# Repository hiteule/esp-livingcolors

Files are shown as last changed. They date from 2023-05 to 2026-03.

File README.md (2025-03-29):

# ESP LivingColors

An electronic board designed to integrate a LivingColor lamp gen1 in [HomeAssistant].
The board is based on an ESP8266 & [ESPHome] to integrate the LivingColors lamp in HomeAssistant.
The communication with the lamp is managed by an Atmega328 microcontroller & a CC2500 module (2.4ghz RF transceiver).
The ESP8266 & Atmega328 communicate through an I2C bus.

:warning: This board ONLY works with the 1st generation LivingColors.

## PCB

The card must be powered with 5V via the J1 connector.

The Atmega328 can be flashed via JP1. The ESP8266 can be flashed via JP3.
For this, you can use my [ESP/Atmega programmer].

The card was designed with [Eagle].
The additional [libraries] used are:
* 74LVC125AD.lbr
* ATMEGA328P-AU.lbr
* CC2500.lbr
* CONNECTORS.lbr
* ESP-12F.lbr
* TXS0104EPWR.lbr
* regulator.lbr

## Software

### Atmega

The Atmega is controling the LivingColors via RF (like your conventional remote control).
We use Arduino bootloader. If it not already the case, you should install it on your Atmega.
To communicate in RF, we use the library made by [George Knutsel]. Thanks to him!

#### Flash the firmware

* Install the Arduino IDE.
* Put the `LivingColors` library in the right Arduino Library folder.
* Plug the board to your computer with JP1 and the [ESP/Atmega programmer] (for the Atmega, you don't need to power it).
* Open the firmware with the Arduino IDE and flash the Atmega.

Now, you can unplug the Atmega and go to the next step.

### ESP

The ESP is exposing the LivingColors in Home Assisant. To do it, we use [ESPHome].
To do so:
* Install the ESPHome module on HomeAssistant.
* Plug the board to your computer with JP3 and the [ESP/Atmega programmer]. Don't forget to power the programmer with an external power source between 3.3V and 12V.
* In the ESPHome module, create a new device.
* Update your ESPHome device with the `livingcolors.yaml` file.
* Install it on the ESP.

Now you can unplug the ESP from your computer and power the board via JP1.
ESP should boot normally and the LivingColors should be visible in HomeAssistant.

## How to use it ?

### Register the remote address

To be able to communicate with the LivingColors, you need to extract and register the remote address.

* Hold the `SW_LEARN` switch and power on the board to enter in the learning mode.
* The LED will light up for 5 seconds. During this time, place the remote control close to the card and press any button several times.

If the procedure fails, the LED will flash slowly (every 1 second). Repeat the learning procedure.
If the LED is off, the procedure was successful and the remote control address has been extracted and registered. You can now use it :)

### Color cycle mode

To activate the color cycle mode (seen when holding ON remote key), you have to turn on the related light effect on HomeAssistant.

## FAQ

**The LED will flash quickly (every 100ms)**\
The card doesn't know the remote address. You should run a learning procedure. Please see the "How to use it ?" section.

**The LED will flash slowly (every 1s)**\
The remote address learning procedure fail (no address found). You should restart a learning procedure. Place the remote control close to the card and press several buttons.

**Do I need to do a remote address learning procedure every time I launch the card?**\
No, the remote address is saved in the Atmega ROM.

**Can I continue to use the remote control?**\
Yes, you can continue to use the remote control alongside the card.

**Can I register another remote control?**\
Yes, simply launch a remote address learning procedure.
Please note that you can only register one remote control at a time.

[HomeAssistant]: https://www.home-assistant.io
[ESPHome]: https://esphome.io/
[ESP/Atmega programmer]: https://github.com/hiteule/programmer-esp-atmega
[Eagle]: https://www.autodesk.fr/products/eagle
[libraries]: https://github.com/hiteule/eagle-library
[George Knutsel]: http://www.knutsel.org/2010/04/11/using-the-cc2500-arduino-shield

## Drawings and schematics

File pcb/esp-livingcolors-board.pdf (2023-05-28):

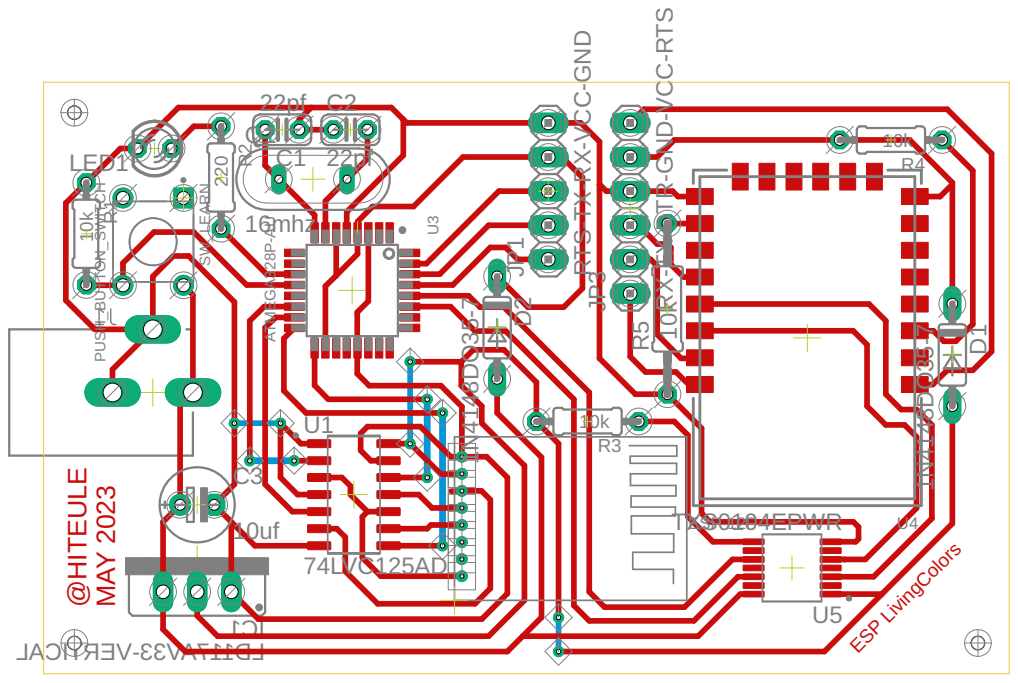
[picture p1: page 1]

RTS-TX-RX-VCC-GND

10Rk X-TX-DTR-GND-VCC-RTS TXS0104EPWR

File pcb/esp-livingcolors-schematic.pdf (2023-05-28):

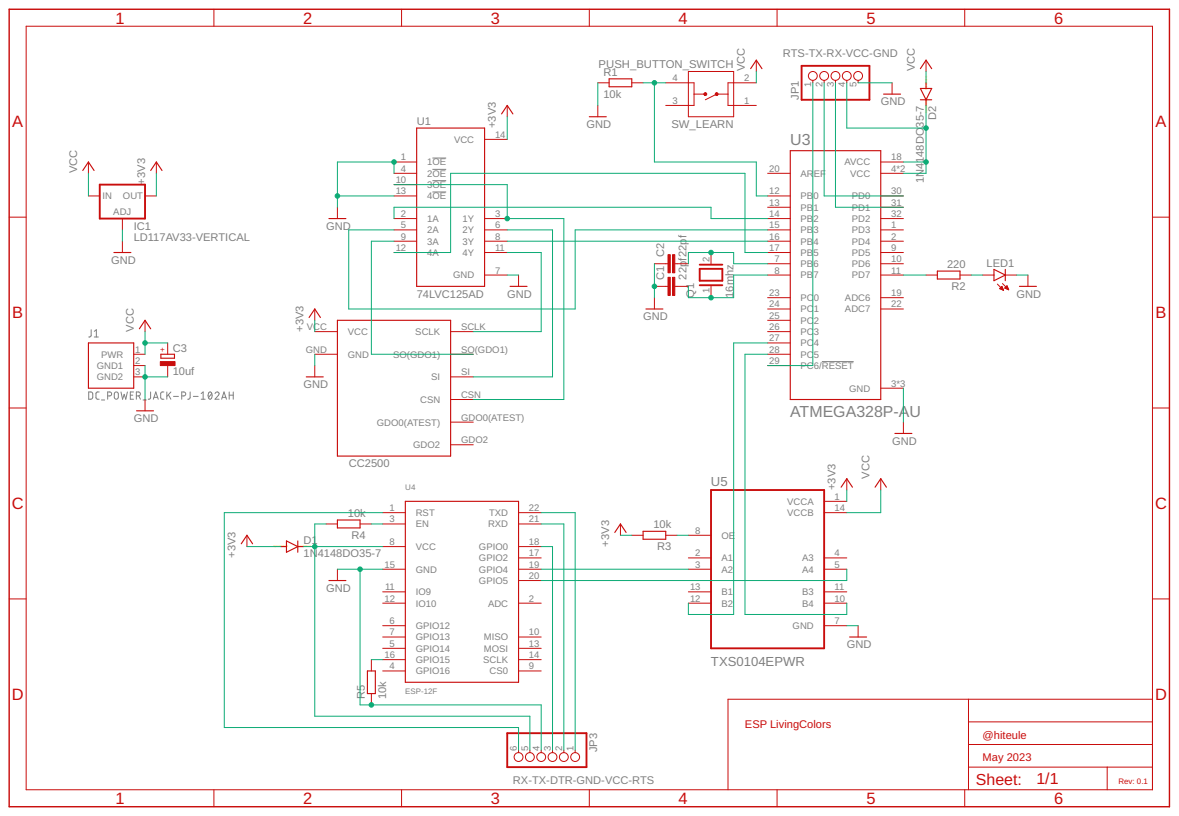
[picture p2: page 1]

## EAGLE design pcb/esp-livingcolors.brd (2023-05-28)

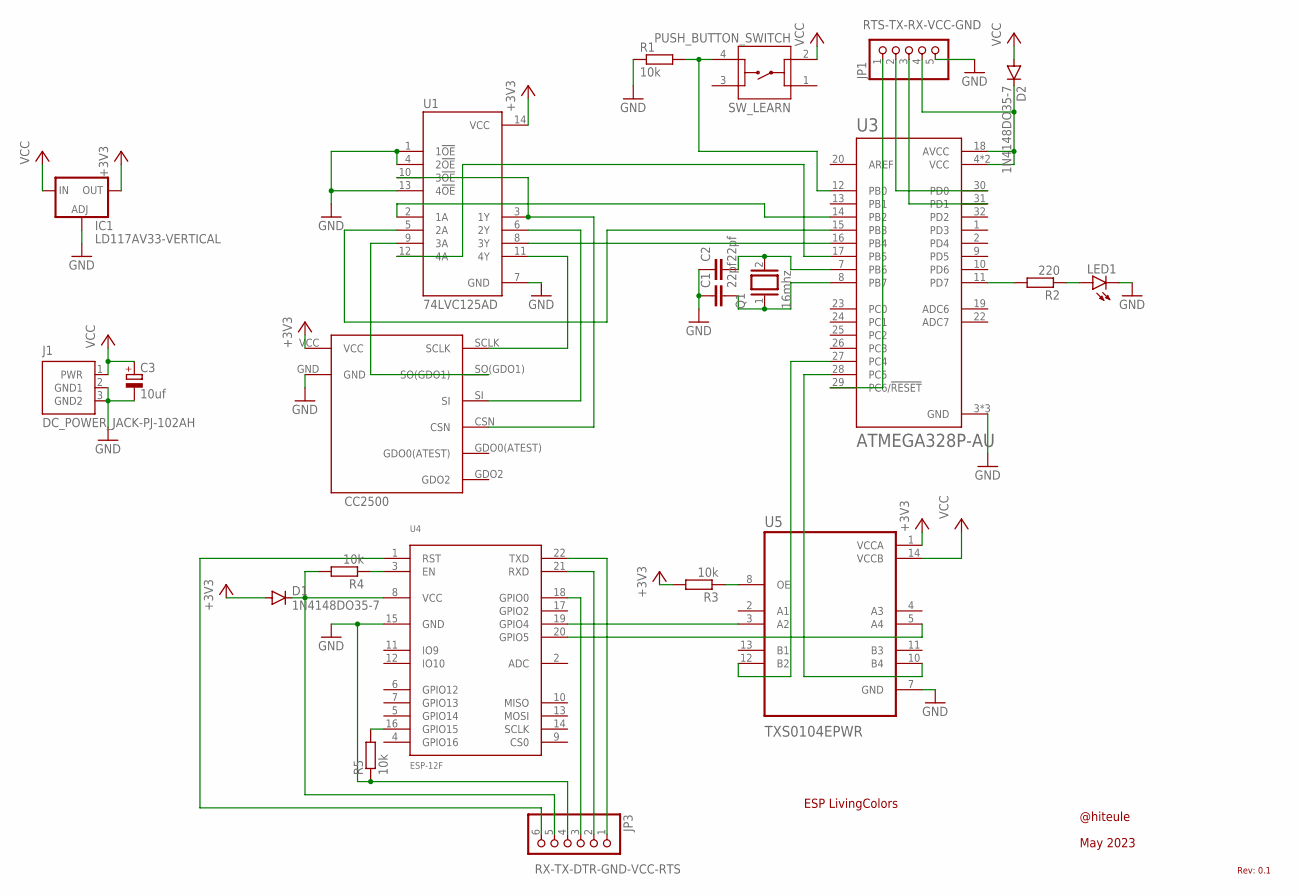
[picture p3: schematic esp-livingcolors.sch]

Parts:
C1, C2: 22pf; C025-024X044
C3: 10uf; E2,5-6E
D1, D2: 1N4148DO35-7; DO35-7
IC1: LD117AV33-VERTICAL; TO220S-VERTICAL
J1: DC_POWER_JACK-PJ-102AH; PJ-102AH
JP1: RTS-TX-RX-VCC-GND; 1X05
JP3: RX-TX-DTR-GND-VCC-RTS; 1X06
LED1: LED3MM
Q1: 16mhz; QS
R1, R3, R4: 10k; 0204/7
R2: 220; 0204/7
R5: 10k; 0207/12
SW_LEARN: PUSH_BUTTON_SWITCH
U1: 74LVC125AD; SOIC127P600X175-14N
U3: ATMEGA328P-AU; QFP80P900X900X120-32N
U4: ESP-12F
U5: TXS0104EPWR; SOP65P640X120-14N
U$1: CC2500-ANTENNA-MODULE

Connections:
+3V3: D1.A, IC1.2 (OUT), R3.2, U1.14 (VCC), U5.1 (VCCA), U$1.VCC
GND: C1.1, C2.1, C3.-, IC1.1 (ADJ), J1.2 (GND1), J1.3 (GND2), JP1.5, JP3.4, LED1.K (C), R1.1, R5.1, U1.1 (1!OE!), U1.4 (2!OE!), U1.7 (GND), U1.13 (4!OE!), U3.3 (GND), U3.5 (GND), U3.21 (GND), U4.15 (GND), U5.7 (GND), U$1.GND
unnamed: R1.2, SW_LEARN.4, U3.12 (PB0)
unnamed: C2.2, Q1.2, U3.7 (PB6)
unnamed: C1.2, Q1.1, U3.8 (PB7)
unnamed: R2.2, U3.11 (PD7)
unnamed: LED1.A, R2.1
unnamed: U1.9 (3A), U$1.SO(GDO1)
unnamed: R4.1, U4.3 (EN)
unnamed: U1.3 (1Y), U1.10 (3!OE!), U$1.CSN
unnamed: U1.2 (1A), U3.14 (PB2)
unnamed: U1.5 (2A), U3.15 (PB3)
unnamed: U1.6 (2Y), U$1.SI
unnamed: U1.8 (3Y), U3.16 (PB4)
unnamed: JP3.6, U4.1 (RST)
unnamed: U1.11 (4Y), U$1.SCLK
unnamed: U1.12 (4A), U3.17 (PB5)
unnamed: U3.27 (PC4), U5.12 (B2)
unnamed: R3.1, U5.8 (OE)
unnamed: U3.28 (PC5), U5.10 (B4)
unnamed: U4.19 (GPIO4), U5.3 (A2)
unnamed: U4.20 (GPIO5), U5.5 (A4)
unnamed: JP3.1, U4.22 (TXD)
unnamed: JP3.3, U4.18 (GPIO0)
unnamed: JP3.2, U4.21 (RXD)
unnamed: D1.C, JP3.5, R4.2, U4.8 (VCC)
unnamed: R5.2, U4.16 (GPIO15)
unnamed: D2.C, JP1.4, U3.4 (VCC), U3.6 (VCC), U3.18 (AVCC)
unnamed: JP1.1, U3.29 (PC6/!RESET)
unnamed: JP1.2, U3.30 (PD0)
unnamed: JP1.3, U3.31 (PD1)
VCC: C3.+, D2.A, IC1.3 (IN), J1.1 (PWR), SW_LEARN.2, U5.14 (VCCB)

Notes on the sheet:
ESP LivingColors
@hiteule
May 2023
Rev: 0.1

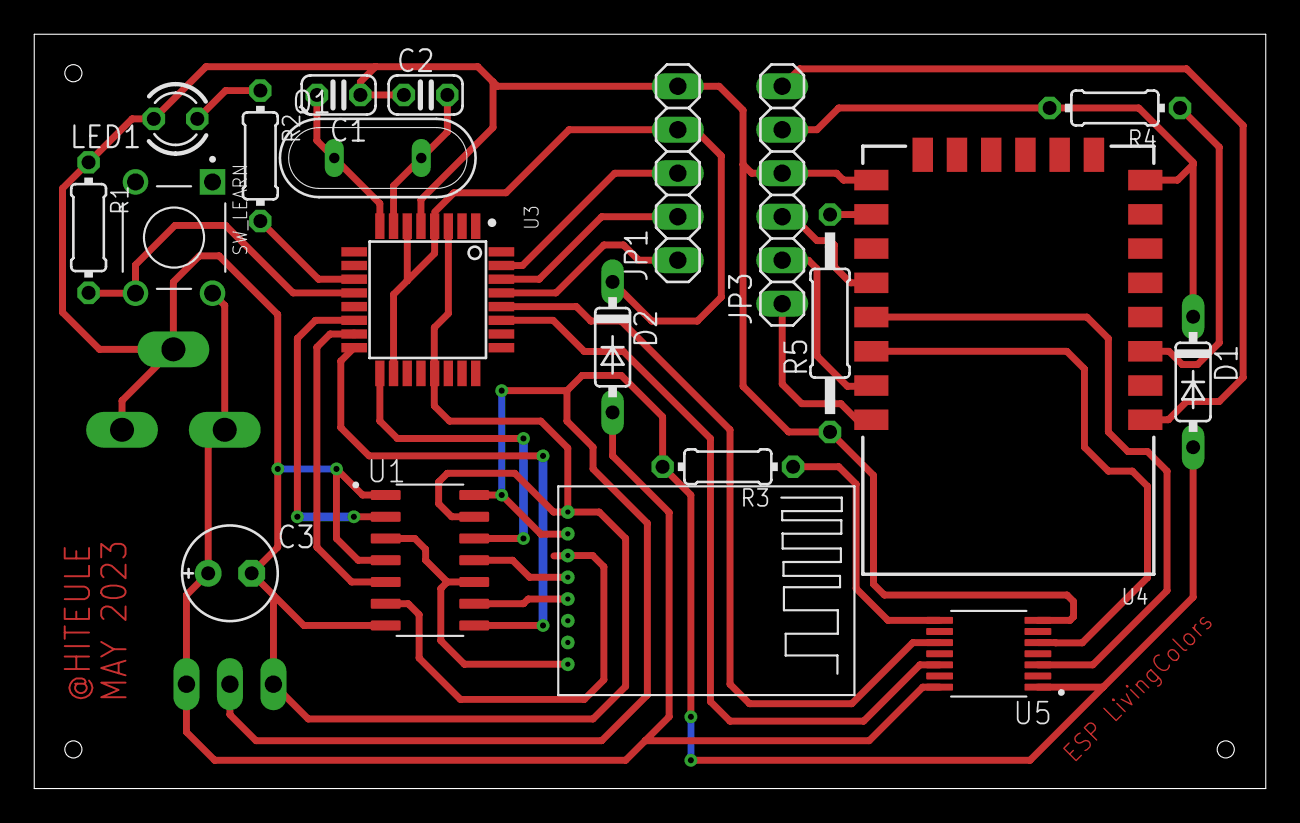
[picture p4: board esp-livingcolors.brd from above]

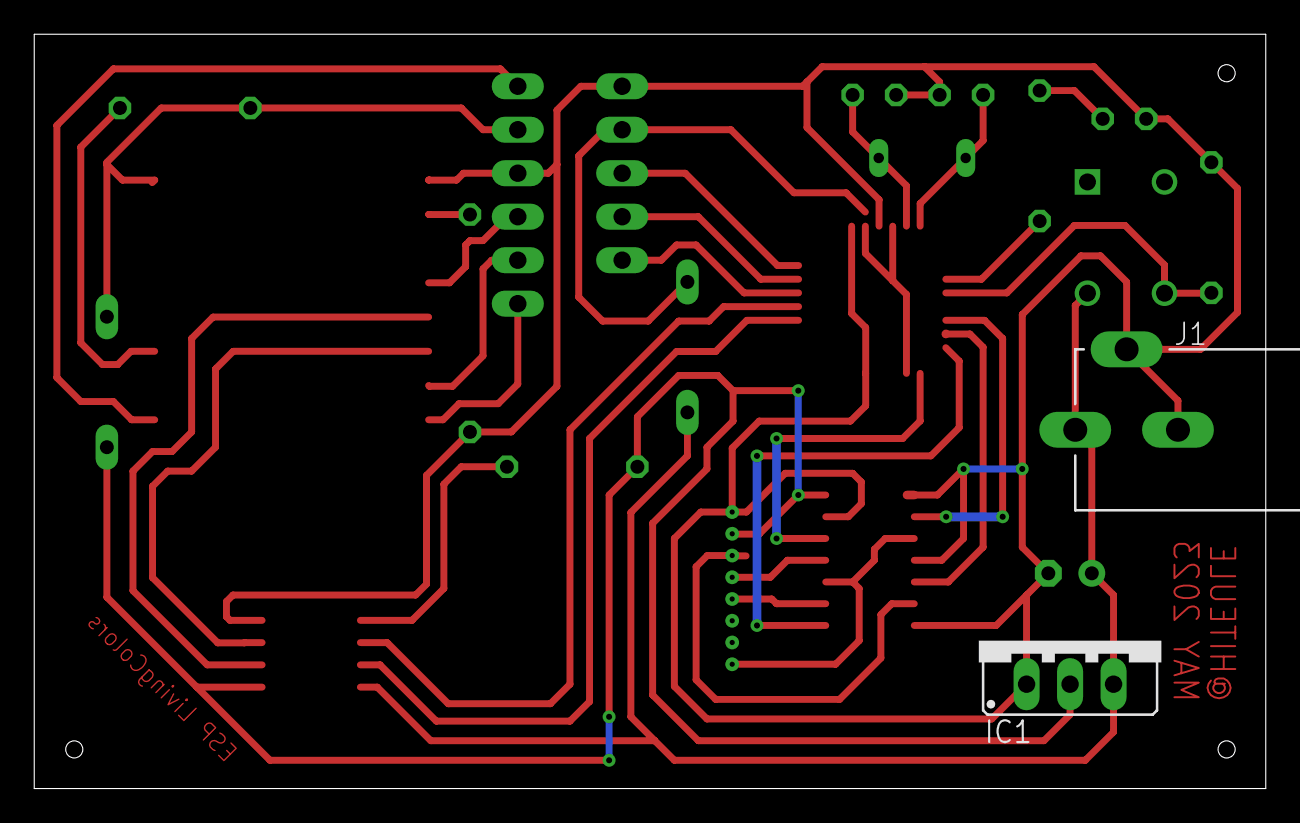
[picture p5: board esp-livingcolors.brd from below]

Board: 2 copper layers, 71.9 x 44.1 mm, 22 parts (2 on the bottom side), 32 nets.

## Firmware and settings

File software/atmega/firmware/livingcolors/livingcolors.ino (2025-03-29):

#include <Wire.h>
#include <CC2500.h>
#include <ColourConversion.h>
#include <LivingColors.h>
#include <EEPROM.h>

#define lcMOSI 11
#define lcMISO 12
#define lcSCK  13
#define lcCS   10

#define LED   7
#define LEARN 8

#define COMMAND_OFF '0'
#define COMMAND_COLOR '1'
#define COMMAND_EFFECT_COLOR_CYCLE '2'

LivingColors livcol(lcCS, lcSCK, lcMOSI, lcMISO);

struct LightData
{
  char command;
  char h0;
  char h1;
  char h2;
  char s0;
  char s1;
  char s2;
  char v0;
  char v1;
  char v2;
};

bool lampState = false;

void setup() {
  Serial.begin(9600);
  delay(1000);

  pinMode(LED, OUTPUT);
  pinMode(LEARN, INPUT);
  digitalWrite(LED, LOW);

  livcol.init();
  livcol.clearLamps();

  // Learn a new remote address
  if (digitalRead(LEARN) == HIGH) {
    digitalWrite(LED, HIGH);
    livcol.learnLamps();
    digitalWrite(LED, LOW);

    // Address not found
    if (livcol.getNumLamps() == 0) {
      while (1) {
        digitalWrite(LED, HIGH);
        delay(1000);
        digitalWrite(LED, LOW);
        delay(1000);
      }
    }

    // Write address on EEPROM
    unsigned char learnedAdress[9] = { 0x00, 0x00, 0x00, 0x00, 0x00, 0x00, 0x00, 0x00, 0x00 };
    livcol.getLamp(0, learnedAdress);
    Serial.println("learned addr:");
    for (int x=0; x<9; x++) {
      Serial.print(learnedAdress[x], HEX);
      Serial.print(", ");
      EEPROM.write(x, learnedAdress[x]);
    }
    Serial.println("");
  }

  // Read address on EEPROM
  unsigned char address[9] = { 0x00, 0x00, 0x00, 0x00, 0x00, 0x00, 0x00, 0x00, 0x00 };
  Serial.println("Read addr:");
  byte val;
  for (int y=0; y<9; y++) {
    val = EEPROM.read(y);
    address[y] = val;
    Serial.print(val, HEX);
    Serial.print(", ");
  }
  Serial.println("");

  // Address not found on EEPROM. Need to learn it ?
  if (address[8] != 0x11) {
    while (1) {
      digitalWrite(LED, HIGH);
      delay(100);
      digitalWrite(LED, LOW);
      delay(100);
    }
  }

  livcol.addLamp(address);

  Wire.begin(0x21);
  Wire.onReceive(receiveEvent);
}

void loop() {
  delay(100);
}

// Function that executes whenever data is received from master
// This function is registered as an event, see setup()
void receiveEvent(int howMany) {
  char buf[13];
  int i=0;
  while (1 <= Wire.available() && i<=12) {
    char c = Wire.read();
    buf[i] = c;
    i++;
  }
  buf[i]=0;

  // c|hhh-sss-vvv
  LightData lightData;
  lightData.command = buf[0];
  lightData.h0 = buf[2];
  lightData.h1 = buf[3];
  lightData.h2 = buf[4];
  lightData.s0 = buf[6];
  lightData.s1 = buf[7];
  lightData.s2 = buf[8];
  lightData.v0 = buf[10];
  lightData.v1 = buf[11];
  lightData.v2 = buf[12];

  send(lightData);
}

void send(LightData lightData) {
  // Turn off
  if (lightData.command == COMMAND_OFF) {
    livcol.turnLampOff(Val('0'));
    lampState = false;

    return;
  }

  // Effect color cycle
  if (lightData.command == COMMAND_EFFECT_COLOR_CYCLE) {
    livcol.turnLampOnRotating(Val('0'));
    lampState = true;

    return;
  }

  // Set color
  byte valH = Val(lightData.h0, lightData.h1, lightData.h2);
  byte valS = Val(lightData.s0, lightData.s1, lightData.s2);
  byte valV = Val(lightData.v0, lightData.v1, lightData.v2);

  if (lampState == false) {
    livcol.turnLampOnHSV(Val('0'), valH, valS, valV);
    lampState = true;

    return;
  }

  livcol.setLampColourHSV(Val('0'), valH, valS, valV);
}

byte Val(char c) {
  byte t = 0;

  if (c >= '0' && c <= '9') {
    t = c - '0';
  }

  return t;
}

byte Val(char c1, char c2, char c3) {
  return Val(c3) + 10 * Val(c2) + 100 * Val(c1);
}

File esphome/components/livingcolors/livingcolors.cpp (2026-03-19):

#include "livingcolors.h"
#include "esphome/core/log.h"

#include <cinttypes>
#include <Wire.h>

namespace esphome {
namespace livingcolors {

  static const char *const TAG = "LivingColorsComponent";
  static const char COMMAND_OFF = '0';
  static const char COMMAND_COLOR = '1';
  static const char COMMAND_EFFECT_COLOR_CYCLE = '2';

  LivingColorsComponent::LivingColorsComponent() {
  }

  void LivingColorsComponent::setup() {
    Wire.begin();
  }

  void LivingColorsComponent::setup_state(light::LightState *state) {
    state_ = state;
    state_->set_gamma_correct(0);
    state_->set_default_transition_length(0);
    state_->add_effects({new LivingColorsCycleLightEffect()});
  }

  void LivingColorsComponent::write_state(light::LightState *state) {
    float brightness;
    state->current_values_as_brightness(&brightness);

    uint8_t hue, saturation, value;
    char command;
    if (brightness > 0.0) {
      float red, green, blue;
      state->current_values_as_rgb(&red, &green, &blue);

      int _hue;
      float _saturation, _value;
      rgb_to_hsv(red, green, blue, _hue, _saturation, _value);

      hue = (uint8_t) lroundf(_hue * (255.0 / 360.0));
      saturation = (uint8_t) lroundf(_saturation * 255.0);
      value = (uint8_t) lroundf(_value * 255.0);
      command = COMMAND_COLOR;
    } else {
      hue = 0;
      saturation = 0;
      value = 0;
      command = COMMAND_OFF;
    }

    ESP_LOGV(TAG, "Setting light to 0x%02X 0x%02X 0x%02X", hue, saturation, value);

    char buf[14];
    sprintf(buf, "%c|%03d-%03d-%03d", command, hue, saturation, value);

    Wire.beginTransmission(0x21);
    Wire.write(buf);
    Wire.endTransmission();
  }

  void LivingColorsCycleLightEffect::apply() {
    if(!this->applied_) {
      ESP_LOGV(TAG, "LivingColorsCycleLightEffect::apply");

      char buf[14];
      sprintf(buf, "%c|xxx-xxx-xxx", COMMAND_EFFECT_COLOR_CYCLE);

      Wire.beginTransmission(0x21);
      Wire.write(buf);
      Wire.endTransmission();

      this->applied_ = true;
    }
  }

  void LivingColorsCycleLightEffect::stop() {
    ESP_LOGV(TAG, "LivingColorsCycleLightEffect::stop");

    char buf[14];
    sprintf(buf, "%c|xxx-xxx-xxx", COMMAND_OFF);

    Wire.beginTransmission(0x21);
    Wire.write(buf);
    Wire.endTransmission();

    this->applied_ = false;
  }

} // namespace livingcolors
} // namespace esphome
